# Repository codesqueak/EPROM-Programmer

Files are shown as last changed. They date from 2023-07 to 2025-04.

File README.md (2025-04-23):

# EPROM Programmer Version 1.4

2708 / 2716 Simple EPROM Programmer

## Introduction

This card has been designed to be a functional replacement for the Bits & PCs Nascom EPROM Programmer.  It is fully compatible with the existing software.

The card is a completely new implementation of the design with a number of improvements over the original:

*	Completely new track layout
*	All components are readily available from commercial component suppliers (..and eBay!)
*	Switches are fitted to standard 12 PIN DIL sockets
*	LED power indicator
*	Power test point

For full documentation, see the [pdf here](EPROM_Programmer.pdf).  

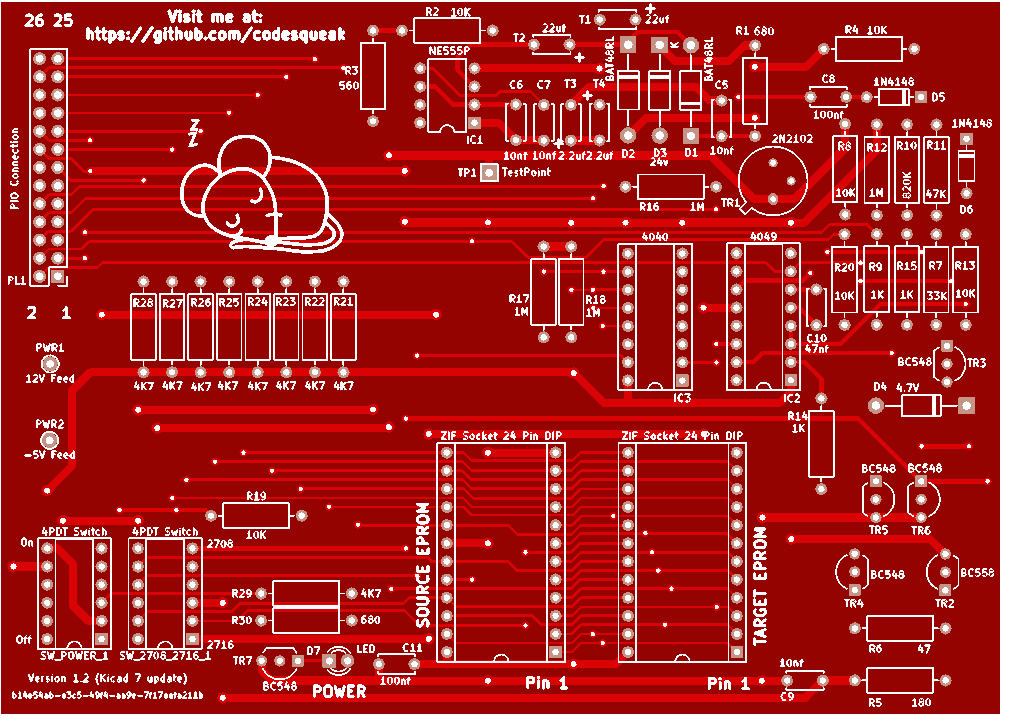
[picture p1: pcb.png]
PCB From JLCPCB
 

  Built PCB

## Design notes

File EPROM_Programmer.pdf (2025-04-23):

2708/2716 EPROM Programmer

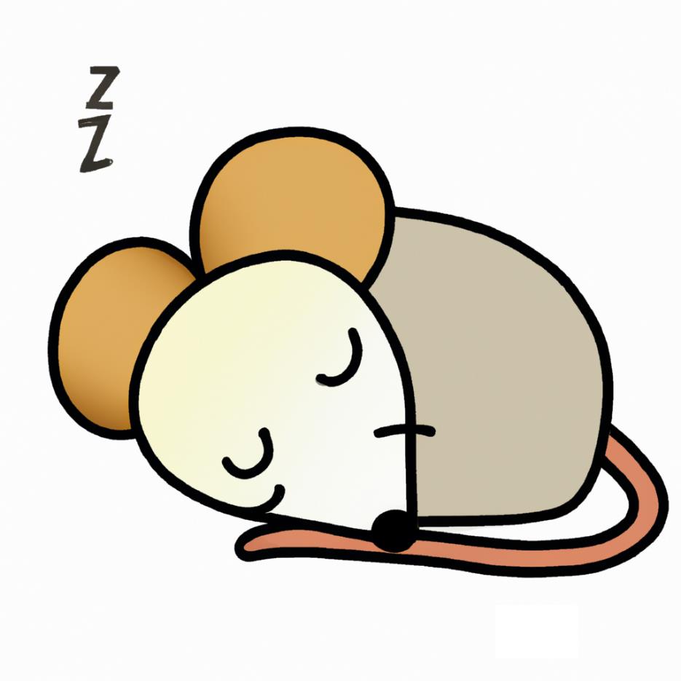
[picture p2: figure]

Issue 2 | Page 1 | 25-June-2023

## 2708/2716 EPROM Programmer

### Instruction Manual & Functional Description

Issue 2 | Page 2 | 25-June-2023

## Contents

Issue 2 | Page 3 | 25-June-2023

## 1 Introduction

This card has been designed to be a functional replacement for the Bits & PCs Nascom EPROM Programmer. It is fully compatible with the existing software.

The card is a completely new implementation of the design with a number of improvements over the original:

- Completely new track layout
- All components are readily available from commercial component suppliers (..and eBay!)
- Switches are fitted to standard 12 PIN DIL sockets
- LED power indicator
- Power test point
- Nice colour!

Issue 2 | Page 4 | 25-June-2023

## 2 Components

Reference(s) | Value | Component
C5, C6, C7, C9 | 10nf | Ceramic disc capacitor
C8, C11 | 100nf | Ceramic disc capacitor
C10 | 47nf | Ceramic disc capacitor
D1, D2 | BAT48RL | Signal diode
D3 | 24v (e.g. BZX85C24) | Zener diode
D4 | 4.7V (e.g. BZX55C4V7) | Zener diode
D5, D6 | 1N4148 | Diode
D7 | LED | LED
IC1 | NE555P | 555 Timer (*)
IC2 | 4049 | Hex inverter
IC3 | 4040 | 12 stage counter
PL1 | PIO Connection | 26-way connector
PWR1 | 12V Feed | Pin
PWR2 | -5V Feed | Pin
R1, R30 | 680 | Resistor
R2, R4, R8, R13, R19, R20 | 10K | Resistor
R3 | 560 | Resistor
R5 | 180 | Resistor
R6 | 47 | Resistor
R7 | 33K | Resistor
R9, R14, R15 | 1K | Resistor
R10 | 820K | Resistor
R11 | 47K | Resistor
R12, R16, R17, R18 | 1M | Resistor
R21, R22, R23, R24, R25, R26, R27, R28, R29 | 4K7 | Resistor
SKT1-ZIF-Donor_1, SKT2-ZIF-Target_1 | ZIF Socket 24 Pin DIP | ZIF sockets
SW_2708_2716_1, SW_POWER_1 | 4PDT Switch | Part ASE4204
T1, T2 | 22uf | Tantalum capacitor
T3, T4 | 2.2uf | Tantalum capacitor
TP1 | Test point | N/A
TR1 | 2N2102 | Transistor
TR2 | BC558 | Transistor
TR3, TR4, TR5, TR6, TR7 | BC548 | Transistor

Issue 2 | Page 5 | 25-June-2023

## 3 Construction

### 3.1 Before you start construction

Inspect the PCB for any visible signs of damage

Select your components:

- Turned pin sockets are recommended due to robustness and reliability
- Tantalum capacitors can be temperamental. Make sure they are inserted with the correct polarity, are of good quality and are overrated voltage wise.

IC1 & IC2 are static sensitive. Handling precautions need to be observed.

### 3.2 Order of construction

The recommended order of construction is:

- Resistors
- Sockets
- Disc capacitors
- Tantalum capacitors
- Insert switches
- LED
- 26 Way connector
- Insert IC’s
- Connections for 12V and -5V

Issue 2 | Page 6 | 25-June-2023

## 4 Switch Connections

The pins for the switches are organized in groups of connections, with the middle being the common.

For example, SW_POWER_1, selected either:

1-2, 4-5, 12-11, 9-8

Or

3-2, 6-5, 10-11, 7-8

### 4.1 Power Switch - SW_POWER_1

This is the On/Off switch for the unit. It enables the input of the +5V, -5V and 12V supplies to the circuitry

Use | Pin | Pin | Use
NC | 1 | 12 | NC
Switched 5V | 2 | 11 | 12V Feed
Power LED | 3 | 10 | Switched 12V
NC | 4 | 9 | NC
-5V Feed | 5 | 8 | VCC (5V)
Switched -5V | 6 | 7 | Switched 5V

### 4.2 EPROM Type Selection - SW_2708_2716_1

This switches between 2708 and 2716 programming mode.

Use | Pin | Pin | Use
2716 PRG Power | 1 | 12 | Generated 24V
ZIF Pin 18 | 2 | 11 | ZIF Pin 21
2708 PRG Power | 3 | 10 | Switched -5V
B5 (|PL1 Pin 1) | 4 | 9 | Pin 15 ((4040)
ZIF Pin 20 | 5 | 8 | ZIF Pin 19
GND / 5V / 12V | 6 | 7 | Switched 12V

Issue 2 | Page 7 | 25-June-2023

## 5 PL1 Connections

### 5.1 Pins

PL1 | Use | PL1 | Use
1 | B5 | 2 | B4
3 | B6 | 4 | B3
5 | NC | 6 | B2
7 | NC | 8 | B1
9 | GND | 10 | B0
11 | GND | 12 | NC
13 | A0 | 14 | NC
15 | A1 | 16 | GND
17 | A2 | 18 | GND
19 | A3 | 20 | VCC
21 | A4 | 22 | VCC
23 | A5 | 24 | A7
25 | A6 | 26 | NC

### 5.2 Control Pin Usage

Signal Line | Use
B0 | Address counter clock (high to low)
B1 | Address counter reset (low to high)
B2 | 2708 Read / program (low = read, high = program) (See below)
B3 | ROM select (low = master selected)
B4 | Program pulse (high to trigger)
B5 | 2716 Read / program (low = read, high = program)
B6 | Pin 20 voltage selection (See below)
B7 | Unused

### 5.3 Use of B2& B6

The combined use of B2 and B6 enables various output level to be generated depending on the read / write mode required and the type of device being addressed.

B2 allows the feed to switch pin 6 to be pulled down to ground via TR7 or left to float to the input voltage (12V). Low = ground, high = float

B6 allows the feed to switch pin 6 to be pulled down to +5V via TR6 / D5 or left to float to the input voltage (12V). Low = ground D5, high = float

Between these two controls, the feed to switch pin 6 can be ground, 5V or 12V

Issue 2 | Page 8 | 25-June-2023

## 6 Usage of the Programmer

1. Ensure everything is powered down
2. Attach the ribbon cable to PL1 – make sure you align Pin 1 PL1 (programmer) to Pin 1 PL4 (Nascom)
3. Attach the 12V supply to PWR1
4. Attach the -5V supply to PWR2
5. Select the EPROM type being used (2708/2716) via the SW_2708_2716_1 switch
6. Insert an EPROM into the Source / Target socket, depending on the operation required (read or program)
7. Switch on the computer
8. Switch on the programmer via SW_POWER_1
9. Happy programming!

Issue 2 | Page 9 | 25-June-2023

## 7 Notes on Components

All the components used have been selected at time of design to be readily available via commercial component suppliers.

### 7.1 IC1 & IC2

These parts are static sensitive. Handling precautions need to be observed.

### 7.2 555 Timer / 24V Generation

Not all 555s appear to be created equal. I have found that not all 555’s appears to work correctly with the 24v generation circuit.

The following have been found to work:

- Texas Instruments NE555P
- LM555CN
- ICM7555IPAZ

To check for correct operation, look at TP1. If it is around 24v then it is working as expected. If it is around 12v then swap for another device.

### 7.3 ZIF Sockets

### 7.3.1 Problems

- They can be expensive and easily damages by soldering!
- The pins are often too large to go into standard IC PCB pin holes

### 7.3.2 Solution

Put ordinary IC sockets in the locations for the ZIF sockets (Not the round pin type as the ZIF sockets will probably not be insertable) and mount the ZIF sockets into these.

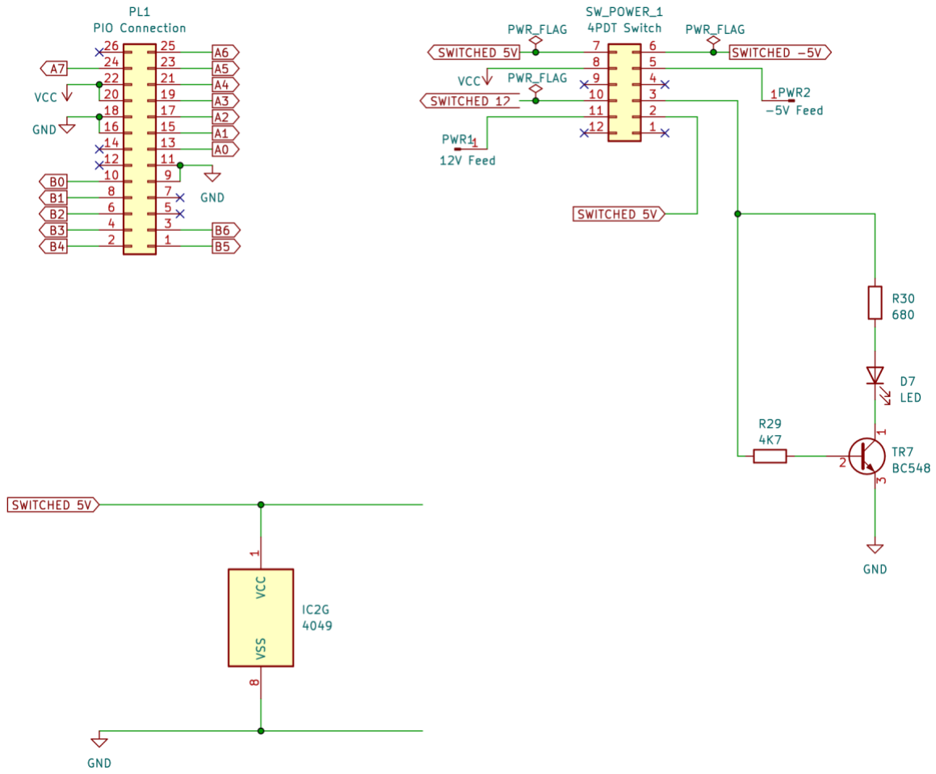
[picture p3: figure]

Issue 2 | Page 10 | 25-June-2023

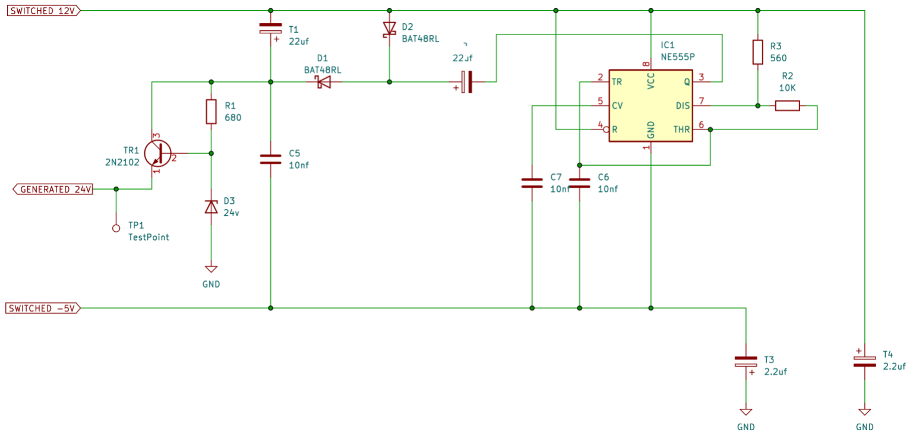
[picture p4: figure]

Issue 2 | Page 11 | 25-June-2023

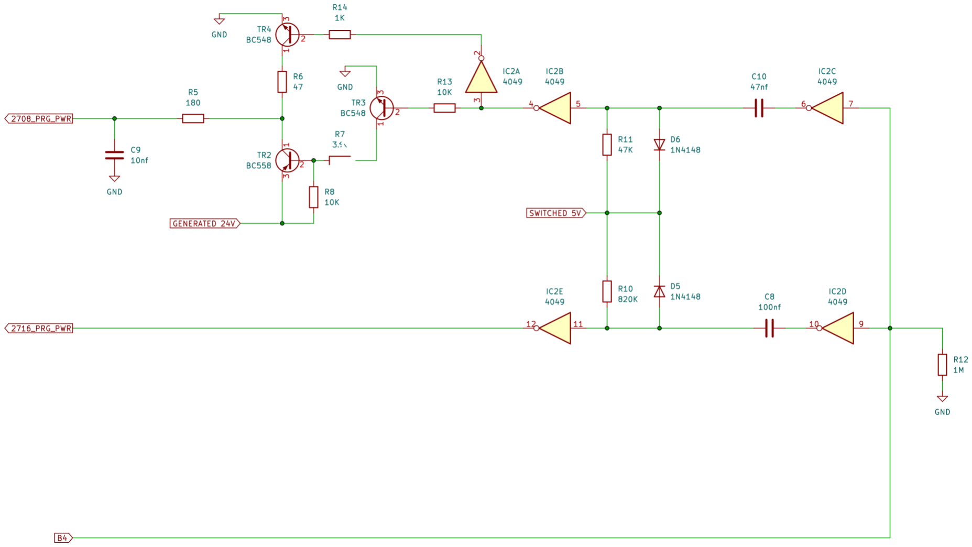
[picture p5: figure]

Issue 2 | Page 12 | 25-June-2023

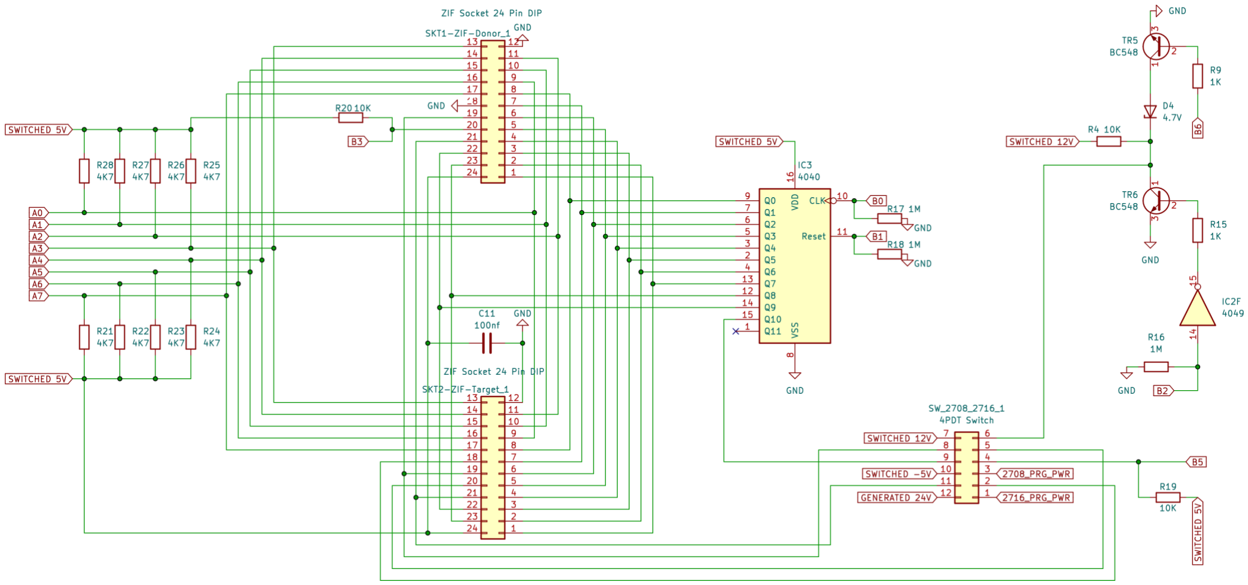
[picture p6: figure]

Issue 2 | Page 13 | 25-June-2023

Issue 2 | Page 14 | 25-June-2023

## 8 Errata

### 8.1 Version 1.1 to Version 1.2

Minor updates

- R10 should be 820K not 820
- Add missing component values from silkscreen
- Tidy silkscreen
- T1 Swapped orientation in design


Issue 2 | Page 15 | 25-June-2023

## 9 Reference Images

### 9.1 PCB

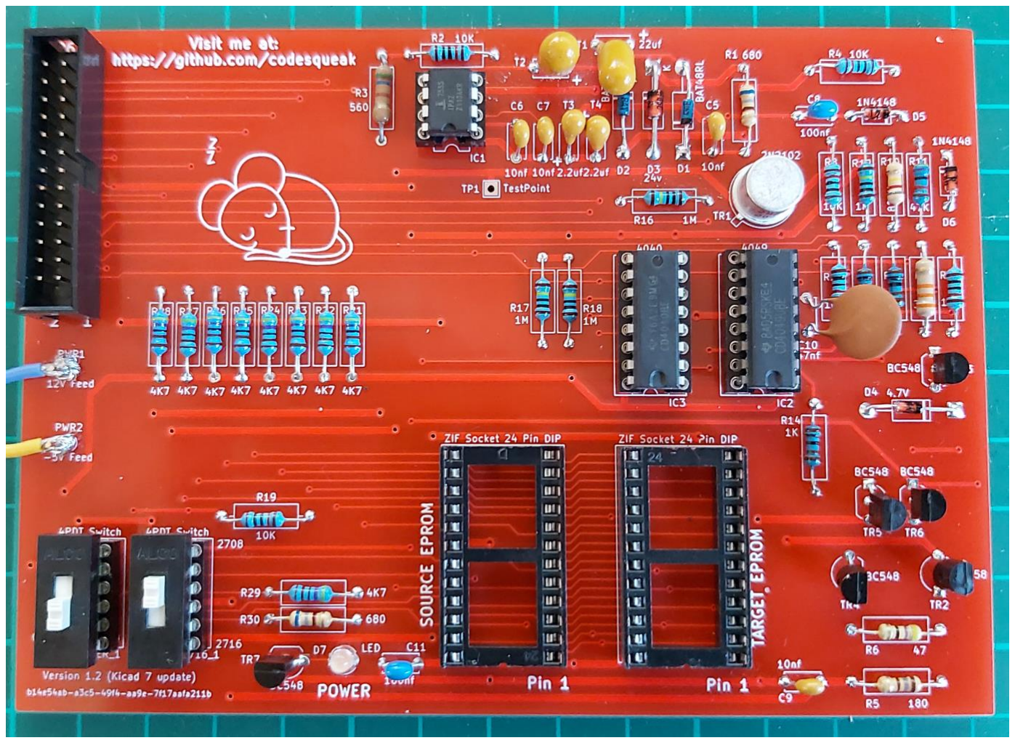
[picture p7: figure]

Issue 2 | Page 16 | 25-June-2023

### 9.2 Built

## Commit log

2023-06-18 Initial upload
    [25v-Supply.kicad_sch, 80bus.kicad_pcb, 80bus.kicad_sch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]
2023-06-18 Delete circuit.pdf
    Unused file
2023-06-18 Remove unused
    [25v-Supply.kicad_sch, 80bus.kicad_pcb, 80bus.kicad_sch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]
2023-06-18 Remove unused files, tweak design layout
    [25v-Supply.kicad_sch, 80bus.kicad_pcb, 80bus.kicad_sch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]
2023-07-15 Update PCB image
2025-04-23 Kicad 9 and Docs
    [25v-Supply.kicad_sch, 80bus.kicad_pcb, 80bus.kicad_sch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]
